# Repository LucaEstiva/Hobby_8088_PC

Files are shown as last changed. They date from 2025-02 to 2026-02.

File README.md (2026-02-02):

# Hobby_8088_PC
Studio e progetti di un PC basato su processore Intel 8088

> E' un progetto realizzato nel tempo libero, quindi ancora incompleto, ma, viste le risorse disponibili, sicuramente funzionante.
> D'altro canto sarebbe sufficiente "copiare" dagli schemi forniti l'intera circuiteria ed assemblare cosi il PC. Tuttavia lo scopo
> del progetto è quello di capire l'architettura del PC XT IBM e, divertirsi con la logica dell'architettura, aggiornarla, oppure volendo,
> modificarla a piacere.

## Fonti:
-  https://it.wikipedia.org/wiki/IBM_Personal_Computer_XT
-  https://www.vlsisystemdesign.com/propagation-delay-of-cmos-inverter/

## Riferimenti:
-  https://www.youtube.com/@breadboardinglabs
-  https://www.youtube.com/@BenEater
-  https://www.youtube.com/@SladorSoft
-  https://www.youtube.com/@elijahmmiller
-  https://www.youtube.com/@alexthelion335
-  https://www.youtube.com/@JohnsBasement
-  https://www.youtube.com/@elijahmmiller
-  ---
-  https://www.youtube.com/@adriansdigitalbasement
-  https://www.youtube.com/@PsychogenicTechnologies
-  https://www.youtube.com/@DrMattRegan
-  https://www.youtube.com/@KludgesFromKevinsCave
-  https://www.youtube.com/@nesoacademy
-  ---

-  https://www.zimmers.net/
-  https://github.com/skiselev
-  https://www.malinov.com/sergeys-projects/

-  ---
- [Digikey FPGA](https://www.youtube.com/watch?v=lLg1AgA2Xoo&list=PLEBQazB0HUyT1WmMONxRZn9NmQ_9CIKhb&ab_channel=DigiKey)
- https://www.minuszerodegrees.net/

- https://archive.org/
- https://archive.org/details/practicaldesignu0000pell/page/n1/mode/2up

- https://www.electronics-tutorials.ws/oscillator/crystal.html
- ---
# e molti molti altri. Grazie !
  
## Software utili ( solo alcuni, lista non aggiornata... ):

- [Logicly](https://logic.ly/demo/)
- [Kicad](https://www.kicad.org/) - CAD Utilizzato per la realizzazione degli schemi elettrici ( e circuiti stampati )
- [Circuitverse Simulator](https://circuitverse.org/simulator) - Importare i file dalla cartella Simulatore_Logica

## Simulazioni
[Proteus 8](https://www.labcenter.com/free-trial/)

## OS
[OSDev.org](https://wiki.osdev.org/Expanded_Main_Page)

## Libri:

- [The 80x86 IBM PC and compatible computers. Volumes I & II, Assembly language, design, and interfacing](https://archive.org/details/80x86ibmpccompat0001mazi/page/n1/mode/2up)

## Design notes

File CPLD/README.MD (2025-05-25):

# COMPLEX PROGRAMMABLE LOGIC DEVICE ( CPLD )

# Preambolo

Per ridurre il numero di componenti e la complessità del cablaggio, visto che per la realizzazione del progetto si utilizzeranno una o più Bredboard,
è piu che plausibile utilizzare le logiche programmabili.
I costruttori di personal computer da anni utilizzano questo tipo di dispositivi riducendo complessità e costi produttivi.

Ridurre il numero di fili che costituiscono le connessioni tra i vari circuiti integrati è sicuramente una buona cosa.

La qualità dei contatti ( considerando come qualità una connessione con resistenza minima ) non è garantita. Riducendo il
numero di connessioni è possibile ridurre la resistenza e le problemeatiche dovute a contatti non ottimali dovuti alla
realizzazione meccanica ( caratteristiche meccaniche delle connessioni ), e alla qualità dei materiali.

La resistenza provoca una caduta di tensione ( Legge di Ohm V = R * I ). Le logiche di tipo TTL distinguono un valore logico 1
da un livello logico 0 solo se la tensione raggiunge il valore necessario ( >= 2,5~ Volt ).

La qualità dei contatti non è garantita neppure nelle schede standard PCB, ( saldature, ossidazione ) infatti molto spesso
le saldature dei componenti tendono a rompersi o a deteriorarsi aumentando cosi la resistenza tra pista in rame e terminali dei
componenti o addirittura l'interruzione della conessione stessa.

I terminali dei compomenti, predendo come esempio il loro inserimento negli "zoccoli o socket", tendono a creare problemi dovuti all'ossidazione.
I computer più vecchi in disuso e posti in ambienti relativamente umidi ( succede spesso nei vecchi Commodore ), smettono di funzionare
proprio a causa di questo inconveniente.

Playstation 3 ( caso eclatante ma non assolutamente isolato ) soffriva di rotture delle saldature dovute alla dilatazione dei
materiali, i quali, espandendosi e ritirandosi a causa del calore prodotto da alcuni circuiti integrati, interrompevano la connessione
tra terminali e PCB, causando malfunzionamento o il guasto totale della macchina.

Inoltre le correnti ad "alte" frequenzea tendono, passando attraverso i cavetti ( induttanze, Correnti indotte, Legge di Faraday ), a generare "rumore". Questo "rumore" potrebbe influenzare i segnali che transitano attraverso i cavetti posti vicini, per tutta la loro lunghezza. Più connessioni dunque potrebbero creare disturbi incontrollati.

E' da ricordare che i cavi sono per lora stessa natura dei resistori.

SE QUESTI FATTORI NON FOSSERO CONSIDERATI CON IL DOVUTO RIGUARDO, POTREBBERO VERIFICARSI SPORADICI MALFUNZIOMANTI O IL MALFUNZIONAMENTO TOTALE.

OK, detto questo, ( la spiegazione scientifica ), passiamo alla parte divertente !

Utilizzando il software Altera ( Intel ) Quartus II è possibile "progettare" graficamente il funzionamento del dispositivo CPLD.
Inoltre sono fornite librerie che contengono molti circuiti logici di base, quindi è possibile posizionare questi circuiti nel
grafico del funzionamento del dispositivo, realizzare, sempre graficamente le connesioni dei vari terminali ed il gioco è fatto.

La serie 7000 di Altera è pienamente compatibile con i livelli di tensione, 5 Volt, dei vecchi processori 8088.

Il tempo di propagazione dei segnali propri dei semiconduttori porte logiche, sono pienamente rispettati.

Le correnti prelevabili da ogni singolo terminale sono sufficienti, se si tengono in considerazione le problematiche descritte sopra.

## Altera serie 7000

> [!NOTE]
> Non è disponibile un adattatore PLCC68 DIP68 o PLC84 DIP84. Il numero di porte di una singola logica programmabile non
> è sufficiente per gestire tutti i segnali necessari. Per il momento ne verrano utilizzate due. Successivamente verrà utilizzata una logica
> programmabile con package 100-Pin TQFP.

EPM7032SLC44

Costo irrisorio.
Programmabile via JTag ( Altera USB Blaster ).
Compatibile con logica TTL 5 Volt.
Velocità di gestione dei segnali pienamente compatibile con le frequenze utilizzate.

## Software per la programmazione datato ma gratuito.

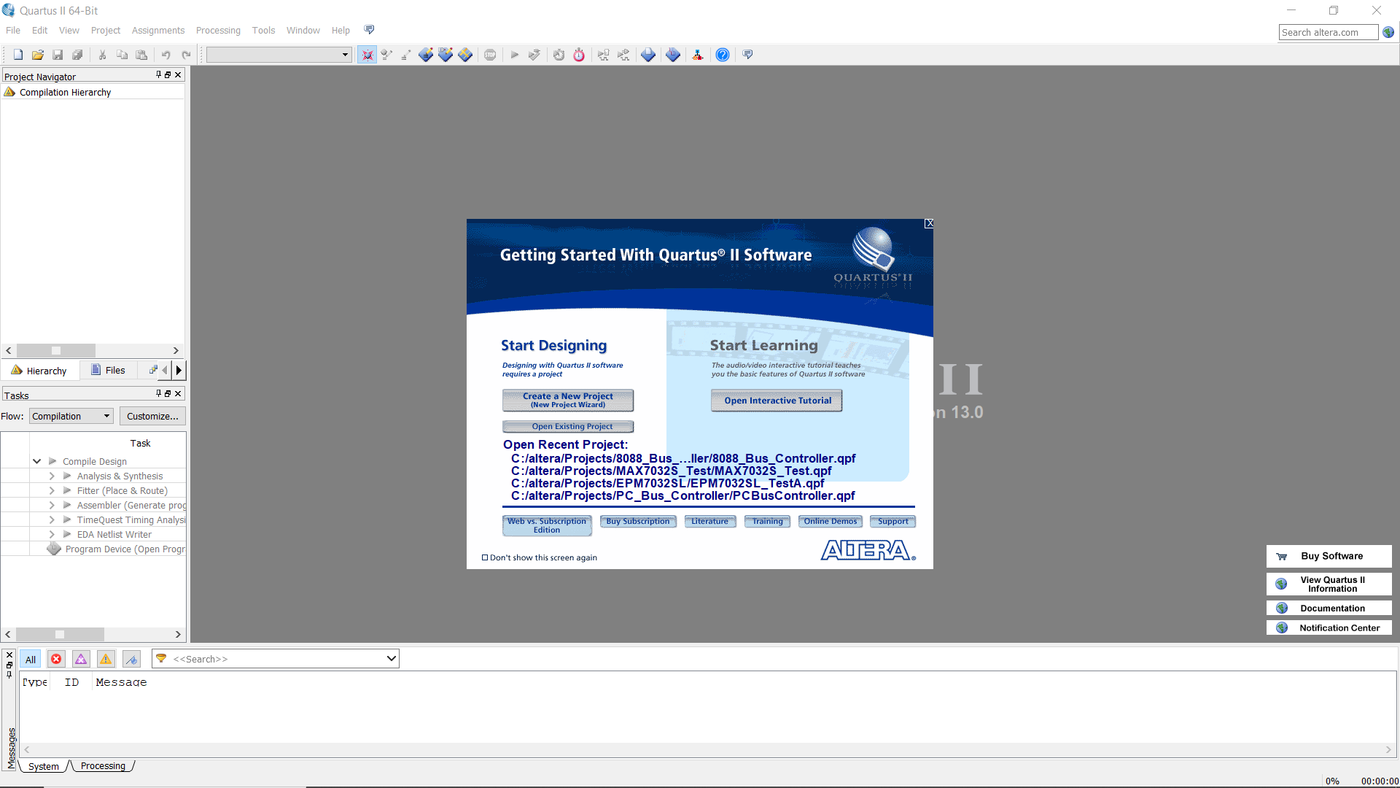
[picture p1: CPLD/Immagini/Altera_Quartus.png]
Altera ( Intel ) Quartus Web 13


DOWNLOAD:
[Datasheet, Manuali, Software](https://drive.google.com/drive/folders/0B2-T0Hc3d6D9NHljNFdQeFpJUWc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)

[QUARTUS TUTORIAL](https://www.youtube.com/watch?v=a8JAkKhxlQI&list=PL57F1D26AD6D50FA7&index=1)

## Programmatore JTag Altera

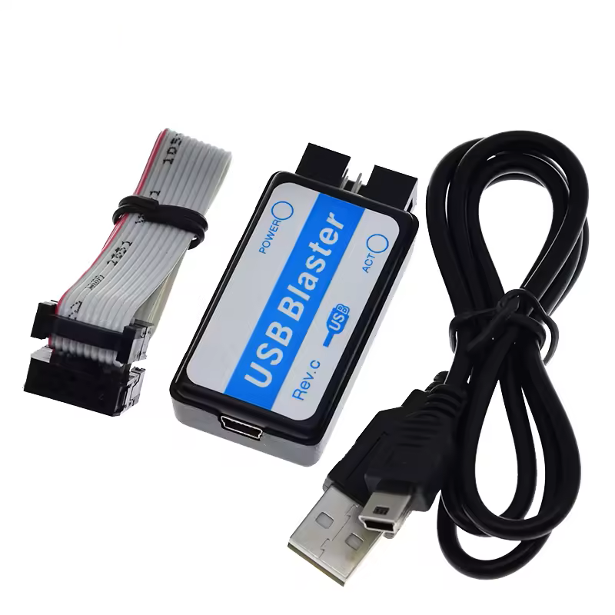
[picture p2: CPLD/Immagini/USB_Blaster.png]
USB Blaster


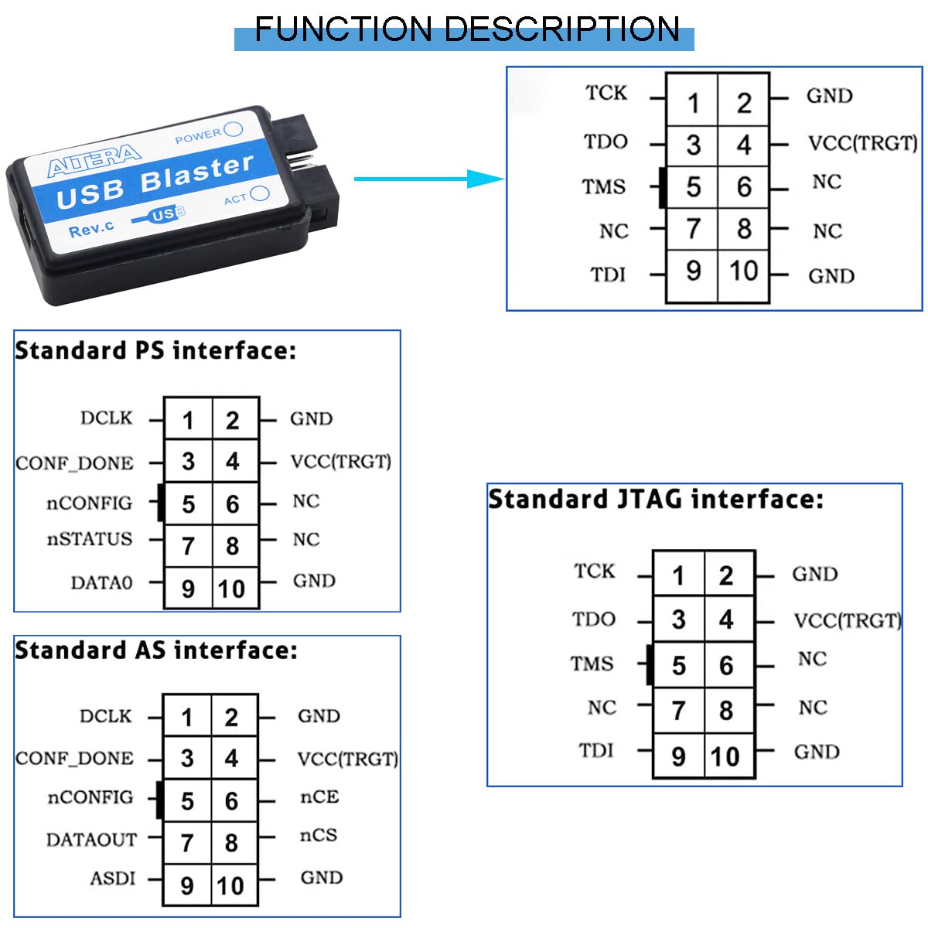
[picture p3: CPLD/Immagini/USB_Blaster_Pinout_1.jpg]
USB Blaster specifiche terminali ( Pinout )


[Altera USB Blaster](https://it.aliexpress.com/item/1005006358681875.html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)

# Adattatore PLCC44 to DIP44

PLCC44toDIP44

[PLCC44 to DIP44](https://it.aliexpress.com/item/1005007005553613.html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)

## COSI SI PUO' DIRE CHE UN'ALTRO PROBLEMA E' RISOLOTO!

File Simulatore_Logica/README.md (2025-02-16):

# SIMULATORE CIRCUITI INTEGRATI DIGITALI ( LOGICA )

https://circuitverse.org/simulator

## Esempi:
- https://circuitverse.org/users/55734/projects/74ls74-61af951a-744b-4180-bd07-4924772b58ce
- https://circuitverse.org/simulator/vending_machine_ssi

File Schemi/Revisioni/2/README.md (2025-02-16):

# TUTTI GLI INTEGRATI LOGICI SONO DELLA SERIE AHCT o F !

Negli schemi elettrici sono stati utilizzati simboli relativi a IC ( Integrate Circuit ) della seire LS solo perchè
i "simboli" e le loro piedinature sono compatibili. Aggiornerò nelle revisioni successive...

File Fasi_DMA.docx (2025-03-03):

# Fasi DMA

## Vengono generati i segnali:

HRQ Il segnale ( pin 10 8237A-5 ) viene portato a livello logico ALTO. Il segnale è utilizzato per richiedere alla CPU l’accesso al BUS.

La CPU non gestisce direttamente il segnale. Il segnale raggiunge la logica dedicata Bus Arbitration and Wait Logic

La circuiteria del Bus Arbitration and Wait Logic è responsabile della corretta generazione dei segnali necessari e delle tempistiche alla quale i segnali devono essere generati ( WAIT STATES ).

I segnali devono essere sincronizzati relativamente alle specifiche dei chip utilizzati CPU, 82C84A

DMAAEN Il segnale viene portato a livello logico BASSO. Il segnale toglie il controllo dei segnali MEMR , MEMW , IOR , IOW , al chip 8288 ( Bus Controller ) e li forza a livello logico ALTO.

Abilita il chip dell’ ADDRESS BUS relativo al DMA, ovvero collega il DMA all’ ADDRESS BUS.

AENBRD Il segnale ( pin 6 8288 AEN ) viene portato a livello logico ALTO. Il segnale disabilita i chip dell’ ADDRESS BUS relativo alla CPU, ovvero scollega la CPU dal BUS ADDRESS BUS.

AEN Il segnale ( pin 15 8288 CEN ) viene portato a livello logico BASSO.

DEN Il segnale ( pin 16 8288 DEN ) scollega la CPU dal BUS DATA BUS.

HOLDA Il segnale ( pin 7 8237A-5 HLDA ) viene portato a livello logico ALTO. Il segnale informa il chip DMA del fatto che il BUS è stato rilasciato dalla CPU

RDYTODMA Il segnale ( pin 6 8237A-5 READY ) viene utilizzato per gestire i tempi di lettura/scrittura della memoria.

DMAWAIT Il segnale ( pin 4 8284 RDY1 )

RDY /WAIT Il segnale ( pin 3 8284 AEN1 )

READY Il segnale ( pin 5 8284 READY ) è la combinazione dei segnali DMAWAIT - RDY /WAIT. Informa la CPU del fatto che il BUS è tornato nuovamente libero in quanto il DMA ha completato il proprio lavoro.

## Altri segnali:

DMACS Il segnale ( pin 11 8237A-5 CS ) viene portato a livello logico BASSO. Abilita il chip DMA per la comunicazione con la CPU. Consente di configurare i registri interni del DMA.

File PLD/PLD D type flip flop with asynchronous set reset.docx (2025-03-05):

# PLD D type flip flop with asynchronous set reset

Questo tipo di circuito viene utilizzato per gestire alcune logiche del PC.

# D type flip flop with asynchronous set reset

From SN74LS74 ( Texas Instruments ) datasheet

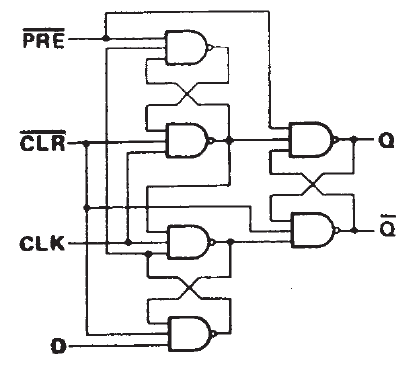
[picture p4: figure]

# D type flip flop with synchronous set reset

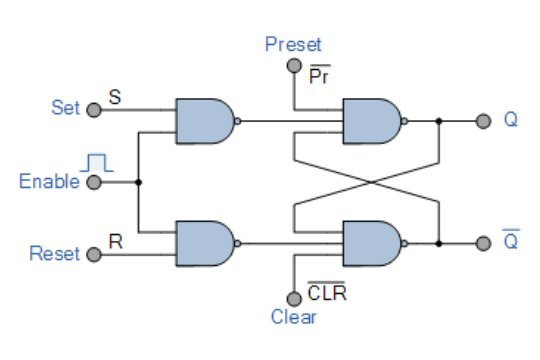
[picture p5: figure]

L’ingresso CLEAR ( CLR ) serve per assicurarsi che l'uscita Q venga sovrascritta con un livello logico 0 ( BASSO ).

L’ingresso PRESET ( PRE ) serve per assicurarsi che l’uscita Q venga sovrascritta con un livello logico 1 ( ALTO ).

Se uno o entrambe gli ingressi CLEAR o PRESET, si trovano a livello logico 0 ( BASSO ), l’ingresso CLOCK non viene considerato. In questi stati di CLEAR e/o PRESET il livello logico delle uscite non cambia mai.

In qualsiasi momento l’ingresso CLEAR viene portato a livello logico 0, non viene considerato lo stato dell’ingresso D. L’uscita Q viene portata a livello logico 0 ( BASSO ), l’uscita !Q viene portata a livello logico 1 ( ALTO ).

In qualsiasi momento l’ingresso PRESET viene portato a livello logico 0, non viene considerato lo stato dell’ingresso D. L’uscita Q viene portata a livello logico 1 ( ALTO ), l’uscita !Q viene portata a livello logico 0 ( BASSO ).

Se entrambe gli ingressi CLEAR e PRESET si tronano a livello logico 1 ( ALTO ), un fronte di salita sull’ingresso CLOCK, copia lo stato dell’ingresso D sull’uscita Q.

L’uscita !Q è sempre l’inverso ( complementare ) dell’uscita Q.

PER UNA DESCRIZIONE PIU’ DETTAGLIATA DEL CHIP 74LS74 e DEI RELATIVI FLIP FLOP IN ESSO CONTENUTI VEDERE IL RELATIVO DATASHEET.

PLD Per ricreare il Flip Flop

Solo alcune PLD supportano alcune funzionalità necessarie per ricreare facilmente la logica del Flip Flop. Dal manuale di WinCupl ( doc0737.pdf è possibile verificare quale serie di PLD si presta meglio alla realizzazione de

WinCupl EXTENSIONS ( Vedere il documento doc0737.pdf )

.D D input of D-type flip-flop

.R R input of SR-type output flip-flop

.S S input of SR-type output flip-flop

.SP Synchronous preset of flip-flop

.AP Asynchronous preset of flip-flop

.SR Synchronous reset of flip-flop

.AR Asynchronous reset of flip-flop

.SP Extension

The .SP extension is used to set the Synchronous Preset of a register to an expression. For example. the equation:

Y.SP = A & B ; /* A and B are inputs */

causes the output Y to be preset synchronous with the local clock used in the macro cell when inputs A and B are true.

This feature is supported on Atmel ATF22V10B, ATV750/B and ATV2500/B devices which share Synchronous preset product terms.

.AP Extension

The .AP extension is used to set the Asynchronous Preset of a register to an expression. For example. the equation "Y.AP = A&B;" causes the register to be asynchro

nously preset when A and B are logically true.

This feature is supported on the Atmel ATF1500 family of devices.

.OE Extension

The .OE extension is used to specify a product term driven output enable signal. It is required for using bi-directional I/O and the individually programmable output-enable

product terms available on Atmel ATV750/B, ATV2500/B and ATF1500 family of devices.

Atmel Devices which have a pin-controlled OE inputs, such as the ATF1500 family also use this suffix.

.D Extension

The .D extension is used to specify the D input to a D-type register. This options causes the compiler to configure the macrocells in the Atmel PLD device to D-type reg isters.

For Atmel PLD’s such as the ATF16V8B/20V8B/22V10B, ATV750/B and ATV2500/B the .D extension must be used for registered logic. Otherwise, CUPL will generate an error.

.AR Extension

The .AR extension is used to define the expression for Asynchronous Reset for a reg ister. This is used in devices that have one or more product terms connected to the

Asynchronous reset of the register.

Devices which have a pin-controlled reset inputs, such as the Atmel ATF1500 family also use this suffix.

Name Flip_Flop;

PartNo 00;

Date 04/03/2025;

Revision 01;

Designer Engineer;

Company None;

Assembly None ;

Location ;

Device g22v10;

/* INPUT */

PIN 1 = clock;

PIN 2 = data;

PIN 3 = !clr;

PIN 4 = !pre;

PIN 13 = !outen;

/* OUTPUT */

PIN 14 = Q1;

PIN 15 = Q2;

/* Logic Equations */

Q1.OE = outen;

Q2.OE = outen;

Q1.SP = pre;

Q1.AR = clr;

Q1.D = data;

Q2 = !Q1;

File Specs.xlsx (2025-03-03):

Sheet: ROM-RAM
RAM | A0-A18 | Adrress | 19 Bit | 0 | 111 11111111 11111111 | 524287
 | A19 | Chip Select-Chip Enable
 |  |  | 20Bit | 0 | 1111 11111111 11111111 | 1048575
ROM

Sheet: IO_Address_Map
000 | 00F | DMA chip 8237A-5
020 | 021 | Interrupt 8259A
040 | 043 | Timer 8253-5
060 | 063 | PPI 8255A
080 | 083 | DMA Page Registers
0Ax* |  | NMI Mask Register
0Cx |  | Reserved
0Ex |  | Reserved
100 | 1FF | Not usable
200 | 20F | Game Control
210 | 217 | Expansion Unit
220 | 24F | Reserved
278 | 27F | Reserved
2F0 | 2F7 | Reserved
2F8 | 2FF | Asyncronous Communications ( secondary )
300 | 31F | Prototype card
320 | 32F | Fixed Disk
378 | 37F | Printer
380 | 38C** | SDLC Communications
380 | 389** | Binary Syncronous Communications ( Secondary )
3A0 | 3A9 | Binary Syncronous Communications ( Primary )
3B0 | 3BF | IBM Monochrome Display/Printer
3C0 | 3CF | Reserved
3D0 | 3DF | Color/Graphics
3E0 | 3F7 | Reserved
3F0 | 3F7 | Diskette
3F8 | 3FF | Asyncronous Communications ( Primary )
* At power-on time, the NON MASK Interrupt into the 8088 in masked OFF. This mask bit can be set and reset through system software as follows
Set mask: | Write hex 80 to I/O Address hex A0 ( Enable NMI )
Clear mask: | Write hex 00 to I/O Address hex A0 ( Disable NMI )
** SLDC Communications and Secondary Binary Syncronous Communications cannot be used toghether because their hex address overlap
 |  | A8, A9 Address bits
 |  | 010000000 | 80
 |  | 100000000 | 100
 |  | 110000000 | 180

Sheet: Interrupt
0 | Timer
1 | Keyboard
2 | Reserved
3 | Asynchronouns Communications ( Secondary )
 | SDLC Communications
 | BSC ( Secondary )
4 | Asynchronouns Communications ( Primary )
 | SDLC Communications
 | BSC ( Primary )
5 | Fixed Disk
6 | Diskette
7 | Printer

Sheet: Memory_Map
 |  |  |  |  | CTRL+Addr Bits |  |  |  | Address bits
0 | 00000 | 16K to 64K Read/Write Memory on System Board |  |  | 19 | 18 | 17 | 16 | 15 | 14 | 13 | 12 | 11 | 10 | 9 | 8 | 7 | 6 | 5 | 4 | 3 | 2 | 1 | 0
16K | 04000 |  |  |  | 0 | 0 | 0 | 0 | 0 | 1 | 0 | 0 | 0 | 0 | 0 | 0 | 0 | 0 | 0 | 0 | 0 | 0 | 0 | 0
32K | 08000 |  |  |  | 0 | 0 | 0 | 0 | 1 | 0 | 0 | 0 | 0 | 0 | 0 | 0 | 0 | 0 | 0 | 0 | 0 | 0 | 0 | 0
48K | 0C000 |  |  |  | 0 | 0 | 0 | 0 | 1 | 1 | 0 | 0 | 0 | 0 | 0 | 0 | 0 | 0 | 0 | 0 | 0 | 0 | 0 | 0
64K | 10000 | Up to 384K Read/Write Memory in I/O channel Up to 384K in I/O Channel |  |  | 0 | 0 | 0 | 1 | 0 | 0 | 0 | 0 | 0 | 0 | 0 | 0 | 0 | 0 | 0 | 0 | 0 | 0 | 0 | 0
80K | 14000
96K | 18000
112K | 1C000 |  |  |  | 0 | 0 | 0 | 1 | 1 | 1 | 0 | 0 | 0 | 0 | 0 | 0 | 0 | 0 | 0 | 0 | 0 | 0 | 0 | 0
128K | 20000 |  |  |  | 0 | 0 | 1 | 0 | 0 | 0 | 0 | 0 | 0 | 0 | 0 | 0 | 0 | 0 | 0 | 0 | 0 | 0 | 0 | 0
144K | 24000
160K | 28000
176K | 2C000 |  |  |  | 0 | 0 | 1 | 0 | 1 | 1 | 0 | 0 | 0 | 0 | 0 | 0 | 0 | 0 | 0 | 0 | 0 | 0 | 0 | 0
192K | 30000 |  |  |  | 0 | 0 | 1 | 1 | 0 | 0 | 0 | 0 | 0 | 0 | 0 | 0 | 0 | 0 | 0 | 0 | 0 | 0 | 0 | 0
208K | 34000
224K | 38000
240K | 3C000 |  |  |  | 0 | 0 | 1 | 1 | 1 | 1 | 0 | 0 | 0 | 0 | 0 | 0 | 0 | 0 | 0 | 0 | 0 | 0 | 0 | 0
256K | 40000 |  |  |  | 0 | 1 | 0 | 0 | 0 | 0 | 0 | 0 | 0 | 0 | 0 | 0 | 0 | 0 | 0 | 0 | 0 | 0 | 0 | 0
272K | 44000
288K | 48000
304K | 4C000 |  |  |  | 0 | 1 | 0 | 0 | 1 | 1 | 0 | 0 | 0 | 0 | 0 | 0 | 0 | 0 | 0 | 0 | 0 | 0 | 0 | 0
320K | 50000 |  |  |  | 0 | 1 | 0 | 1 | 0 | 0 | 0 | 0 | 0 | 0 | 0 | 0 | 0 | 0 | 0 | 0 | 0 | 0 | 0 | 0
336K | 54000
352K | 58000
368K | 5C000 |  |  |  | 0 | 1 | 0 | 1 | 1 | 1 | 0 | 0 | 0 | 0 | 0 | 0 | 0 | 0 | 0 | 0 | 0 | 0 | 0 | 0
384K | 60000 |  |  |  | 0 | 1 | 1 | 0 | 0 | 0 | 0 | 0 | 0 | 0 | 0 | 0 | 0 | 0 | 0 | 0 | 0 | 0 | 0 | 0
400K | 64000
416K | 68000
432K | 6C000 |  |  |  | 0 | 1 | 1 | 0 | 1 | 1 | 0 | 0 | 0 | 0 | 0 | 0 | 0 | 0 | 0 | 0 | 0 | 0 | 0 | 0
448K | 70000 |  | ROM ADDRESS SEL |  | 0 | 1 | 1 | 1 | 0 | 0 | 0 | 0 | 0 | 0 | 0 | 0 | 0 | 0 | 0 | 0 | 0 | 0 | 0 | 0
464K | 74000
480K | 78000
496K | 7C000 |  |  |  | 0 | 1 | 1 | 1 | 1 | 1 | 0 | 0 | 0 | 0 | 0 | 0 | 0 | 0 | 0 | 0 | 0 | 0 | 0 | 0
512K | 80000 |  | RAM 2 SEL |  | 1 | 0 | 0 | 0 | 0 | 0 | 0 | 0 | 0 | 0 | 0 | 0 | 0 | 0 | 0 | 0 | 0 | 0 | 0 | 0 | 9FFFF
528K | 84000
544K | 88000
560K | 8C000 |  |  |  | 1 | 0 | 0 | 0 | 1 | 1 | 0 | 0 | 0 | 0 | 0 | 0 | 0 | 0 | 0 | 0 | 0 | 0 | 0 | 0
576K | 90000
592K | 94000
608K | 98000
624K | 9C000 |  |  |  | 1 | 0 | 0 | 1 | 1 | 1 | 0 | 0 | 0 | 0 | 0 | 0 | 0 | 0 | 0 | 0 | 0 | 0 | 0 | 0
640K | A0000 | 128K Reserved |  |  | 1 | 0 | 1 | 0 | 0 | 0 | 0 | 0 | 0 | 0 | 0 | 0 | 0 | 0 | 0 | 0 | 0 | 0 | 0 | 0
656K | A4000
672K | A8000
688K | AC000 |  |  |  | 1 | 0 | 1 | 0 | 1 | 1 | 0 | 0 | 0 | 0 | 0 | 0 | 0 | 0 | 0 | 0 | 0 | 0 | 0 | 0
704K | B0000 | Monochrome |  | Display Buffer ( 16K Bytes )
720K | B4000
736K | B8000 | Color/Graphics
752K | BC000 |  |  |  | 1 | 0 | 1 | 1 | 1 | 1 | 0 | 0 | 0 | 0 | 0 | 0 | 0 | 0 | 0 | 0 | 0 | 0 | 0 | 0
768K | C0000 |  |  | VGA | 1 | 1 | 0 | 0 | 0 | 0 | 0 | 0 | 0 | 0 | 0 | 0 | 0 | 0 | 0 | 0 | 0 | 0 | 0 | 0 | VGA BIOS usually mapped to 0xC0000 to 0xC7FFF
784K | C4000
800K | C8000 | Fixed Disk Control |  |  | 1 | 1 | 0 | 0 | 1 | 0 | 0 | 0 | 0 | 0 | 0 | 0 | 0 | 0 | 0 | 0 | 0 | 0 | 0 | 0
816K | CC000 | 192K Read Only Memory Expansion and Control
832K | D0000
848K | D4000
864K | D8000
880K | DC000
896K | E0000
912K | E4000
928K | E8000
944K | EC000 |  |  |  | 1 | 1 | 1 | 0 | 1 | 1 | 0 | 0 | 0 | 0 | 0 | 0 | 0 | 0 | 0 | 0 | 0 | 0 | 0 | 0
960K | F0000 | 64K Base System ROM | ROM ADDRESS SEL |  | 1 | 1 | 1 | 1 | 0 | 0 | 0 | 0 | 0 | 0 | 0 | 0 | 0 | 0 | 0 | 0 | 0 | 0 | 0 | 0
976K | F4000
992K | F8000
1008K | FC000 |  |  |  | 1 | 1 | 1 | 1 | 1 | 1 | 0 | 0 | 0 | 0 | 0 | 0 | 0 | 0 | 0 | 0 | 0 | 0 | 0 | 0

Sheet: DMA
 | Min Address | Max Address
Page 0 | 0 | 1111111111111111 | FFFF
Page 1 | 10000000000000000 | 11111111111111111 | 1FFFF
Page 2 | 10 00000000 00000000 | 11 11111111 11111111 | 3FFFF
Page 3 | 100 00000000 00000000 | 111 11111111 11111111 | 7FFFF
Page 4 | 1000 00000000 00000000 | 1111 11111111 11111111 | FFFFF

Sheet: RAS_CAS
RAS (Row Address Strobe) and CAS (Column Address Strobe) are essential signals used in DDR (Double Data Rate) memory to access data stored in specific rows and columns within the memory array. These concepts are fundamental to how DDR memory reads and writes data efficiently.
CAS0 |  | 0
 |  | 1111111111111 | 0x1FFF | 8191
CAS1 | Bit 14 | 10000000000000 | 0x2000 | 8192
 |  | 11111111111111 | 0x3FFF | 16383 | 16383
CAS2 | Bit 15 | 100000000000000 | 0x4000 | 16384
 |  | 101111111111111 | 0x5FFF | 24575 | 24575
CAS3 |  | 110000000000000 | 0x6000 | 24576
 |  | 111111111111111 | 0x7FFF | 32767 | 32768

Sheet: Port
210
211
212
213

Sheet: Foglio3
Bus Arbitration - Wait Logic INPUT
I/O CH RDY | ISA BUS CHANNEL 1-7 READY
XIOR | READ FROM MEM, I/O - IOR BUFFERED
XIOW | WRITE TO MEM, I/O - IOW BUFFERED
DMAEN
MEMR | FROM 8288 MRDC
IOW | FROM 8288 AIOWC
MEMW | FROM 8288 AMWC
IOR | FROM 8288 IORC
 | FROM 8288 IOWC ( NC )
DACK 0 BRD | FROM 8237A-5 ( DMA ) - DACK0
XMEMR | FROM 8288 MRDC - MEMR BUFFERED
LOCK | FROM 8088
S0 | FROM 8088
S1 | FROM 8088
HRQDMA | FROM 8237A-5 ( DMA ) - HRQ
RESET | FROM 8284A - RESET
CLOCK | CLK88 BUFFERED
N.P. NPI | FROM 8087 COOPROCESSOR - INT
N.P. INST LSW | FROM 8255A-5 - PB3
PCK | CLOCK /2 ?
XD7
WRT NMI REG | FROM LOGIC
I/O CLK | CLOCK FROM ISA BUS
ENABLE I/O CLK | FROM 8255A-5 - PB5
CLK88 | FROM 8284A CLOCK GENERATOR
Bus Arbitration - Wait Logic OUTPUT
XMEMR | Enable data transfer from RAM to CPU/DMA. RAM ADDSEL complementary signal
RDY/WAIT | TO 8484A CLOCK GENERATOR
RDY TO DMA | TO 8237A-5 DMA - RDY
DMAEN | Enable data transfer from RAM/ROM etc to DMA
 | TO LS670 DMA PAGE SELECT - READ

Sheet: Control_Signal
8088
S2 | S1 | S0
0 | 0 | 0 | Interrup Acknowledge
0 | 0 | 1 | Read I/O Port
0 | 1 | 0 | Write I/O Port
0 | 1 | 0 | Halt
1 | 0 | 0 | Code Access
1 | 0 | 1 | Read Memory
1 | 1 | 0 | Write Memory
1 | 1 | 1 | Passive
HOLD ( RQ/GT0 ) |  |  | Another master is requiring a local BUS | Free ( float ) BUS and Control Lines | When HOLD goes LOW
HLDA ( RQ/GT1 ) |  |  | Bus free indicator |  | Goes LOW
SS0 ( HIGH )
RD |  |  | READ ( FLOAT IN HOLD ACKNOWLEDGE ) | Depend on the state of IO/M signal | Read from Memory or IO
WR ( LOCK ) |  |  | WRITE ( FLOAT IN HOLD ACKNOWLEDGE ) | Depend on the state of IO/M signal | Write to Memory or I/O
 |  |  | BUS Locked
IO/M ( S2 ) |  |  | I/O or Memory access ( Managed by 8288 ) ( FLOAT IN HOLD ACKNOWLEDGE )
DT/R ( S1 ) |  |  | ( Managed by 8288 ) ( FLOAT IN HOLD ACKNOWLEDGE ) |  | Used to control the direction of data flow through the receiver
DEN ( S0 ) |  |  | Data Enable Data enable for the data BUS transceiver ( Managed by 8288 ) ( FLOAT IN HOLD ACKNOWLEDGE ) | Data transmit receive
ALE ( QS0 ) |  |  | Address latch enable ( NEVER FLOATED )
INTA ( QS1 ) |  |  | Interrupt request Acknowledge
INTR |  |  | Interrupt request
NMI |  |  | Non maskable interrupt request
TEST
READY |  |  | Ack from addressed memory or I/O, data transfer can be completed
8288 BUS CONTROLLER
S2 | S1 | S0 | Status input ( When passive all HIGH ) Status from 8088 | 8288 Command
0 | 0 | 0 | Interrupt Acknowledge | INTA
0 | 0 | 1 | Read I/O Port | IORC
0 | 1 | 0 | Write I/O Port | IOWC, AIOWC
0 | 1 | 1 | HALT | NONE
1 | 0 | 0 | Code Access | MRDC
1 | 0 | 1 | Read Memory | MRDC
1 | 1 | 0 | Write Memory | MWTC, AMWC
1 | 1 | 1 | PASSIVE | NONE
ALE |  |  | Address latch enable, strobe address into the address latches
DEN |  |  | Data enable, ENABLE Data transceivers local or system bus
DT/R |  |  | Data transmit/receive, HIGH Trasmit data, LOW Receive data
AEN |  |  | Address Enable, ENABLE ADDRESS LATCHES, Enable command outputs of the 8288 Bus Controller
CEN |  |  | Command Enable, When LOW Command output and DEN PDEN are forced to inactive state
IOB |  |  | Input/Output BUS MODE, When HIGH 8288 function in I/O Bus Mode, When LOW 8288 function in System Bus Mode
AIOWC |  |  | Advanced I/O Write Command, early indication of I/O WRITE instruction
IOWC |  |  | I/O Write Command, I/O Device read from Data Bus Command
IORC |  |  | I/O Read Coomand, I/O Device write to Data Bus Command
AMWC |  |  | Advanced Memory Write Command, early indication of RAM WRITE Instruction
MWTC |  |  | Memory Write Command, Write data to memory command
MRDC |  |  | Memory Read Command, Read data from memory command
INTA |  |  | Interrupt Acknowledge, Tell an interrupting DEVICE that its interrup has been acknwoledged, It shuold drive information onto the DATA BUS
MCE/PDEN |  |  | Master Cascade Enable, occurs during an interrupt sequence, Read a cascade Address from a MASTER PIC
 |  |  | Peripheral Data Enable, ENABLE the DATA BUS TRANSCEIVERS for the I/O BUS that DEN performs for the SYSTEM BUS
DMA
CLK |  |  | Clock up to 5MHz
CS |  |  | Chip select, select the 8237A as an I/O devuce during CPU IDLE CYCLE
RESET
READY |  |  | Input used to extend the memory read and write pulse from the 8237A to accomdodate slow memory or I/O
HLDA |  |  | HOLD ACKNOWLEDGE The active HIGH Ack from the cpu indicates that the SYSTEM BUS is free
DREQ0-DREQ3 |  |  | DMA REQUEST, DMA Line to request DMA service, DREQ0 as the HIGH PRIORITY, DACK ack the DREQ signal | Polarity programmable
IOR |  |  | I/O READ, In the IDLE CYCLE
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

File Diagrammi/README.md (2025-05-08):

# Diagrammi realizzati con il software free:

- [Draw.io Web](https://app.diagrams.net/)
- [Draw.io Desktop](https://www.drawio.com/)

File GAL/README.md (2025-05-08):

# Risorse

- [GALAsm](https://github.com/daveho/GALasm)
- [Lattice ispGAL & ispLSI](https://www.ythiee.com/2023/01/08/lattice-ispgal-isplsi/)
- [GAL specific information](https://www.ythiee.com/2021/06/06/gal-specific-information/)
- [PLD Compilers](https://www.ythiee.com/2021/06/06/pld-compilers/)

- [VirtualBox](https://www.virtualbox.org/)
- [Windows XP Professional SP3](https://archive.org/details/WinXPProSP3x86)
- [Windows XP Product Key](https://github.com/Fuwn/xp)

## Alcuni articoli interessanti:
- [KIM-64](https://www.ythiee.com/2025/01/05/kim-64/)
- [GAL22V10](https://www.ythiee.com/tag/gal22v10/)

# High Performance E2CMOS PLD Generic Array Logic™

- [GAL26V12C](https://github.com/LucaEstiva/Hobby_8088_PC/blob/main/GAL/26CV12.PDF)

- [GAL20RA10](https://github.com/LucaEstiva/Hobby_8088_PC/blob/main/GAL/GAL20RA10.PDF)

## Alcune peculiarità del chip GAL 20RA10

- Reset Asincrono indipendente per ogni Flip Flop:

Each GAL20RA10 macrocell has an independent asynchronous\
reset and preset control product term. The reset and preset product\
terms are level sensitive, and will hold the flip-flop in the reset or\
preset state while the product term is active independent of the clock\
or D-inputs. It should be noted that the reset and preset term alter\
the state of the flip-flop whose output is inverted by the output\
buffer. A reset of the flip-flop will result in the output pin becoming\
a logic high and a preset will result in a logic low.\

- Sogenti clock indipenti:

An independent clock control product term is provided for each\
GAL20RA10 macrocell. Data is clocked into the flip-flop on the\
active edge of the clock product term. The use of individual clock\
control product terms allow up to ten separate clocks. These clocks\
can be derived from any pin or combination of pins and/or feedback\
from other flip-flops. Multiple clock sources allow a number of\
asynchronous register functions to be combined into a single\
GAL20RA10. This allows the designer to combine discrete logic\
functions into a single device.\

# ABEL
ABEL (Advanced Boolean Expression Language)\
Può essere utilizzato su macchina virtuale con Windows XP.
E' possibile scaricare ABEL direttamente da questo repository.

- Utilizzare ABEL GUI:

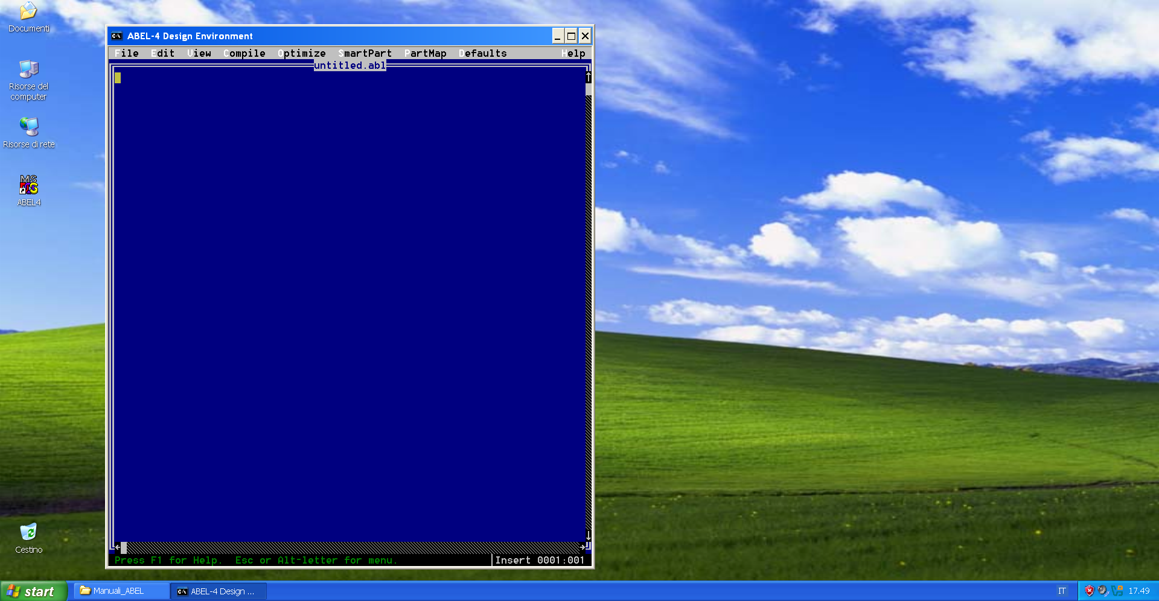
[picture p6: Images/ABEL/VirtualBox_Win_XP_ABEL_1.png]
ABEL ON XP


Per generare il file jed, sarà necessario eseguire gli step:

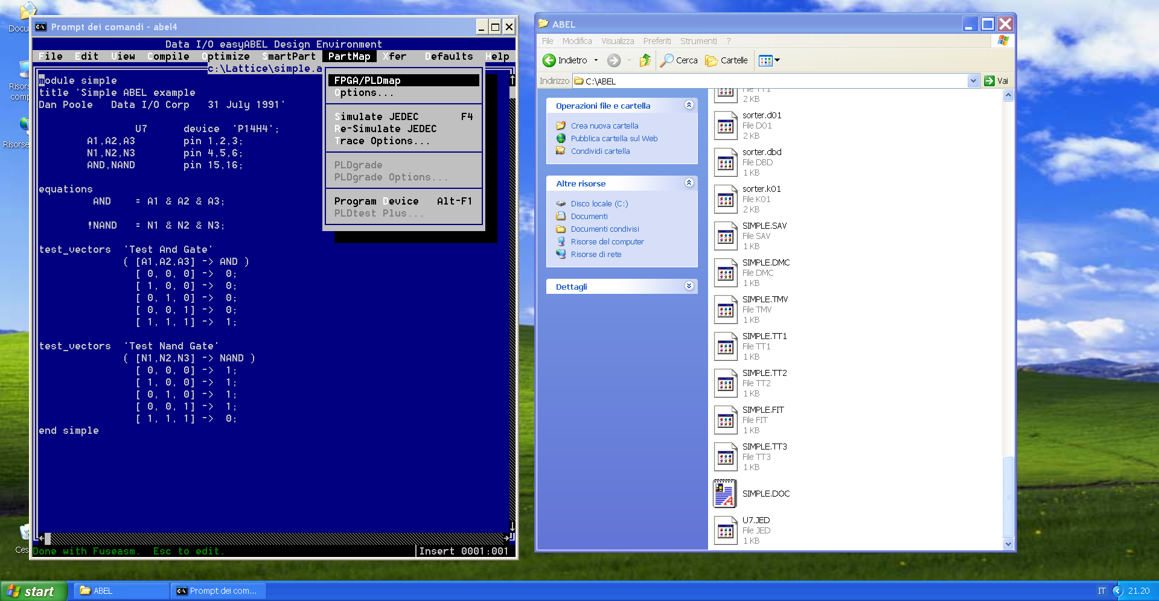
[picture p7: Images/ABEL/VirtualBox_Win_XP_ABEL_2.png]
ABEL COMPILE


- Compile
- Optimize
- Fit
- FPGA/PLDmap

Per utilizzare ABEL utlizzando la riga di comando dal prompt di MS-Dos sarà necessario aggiungere al path i seguenti percorsi ( Pannello di controllo - Sistema - Avanzate - Variabili ambiente )\

- ahdl2pla

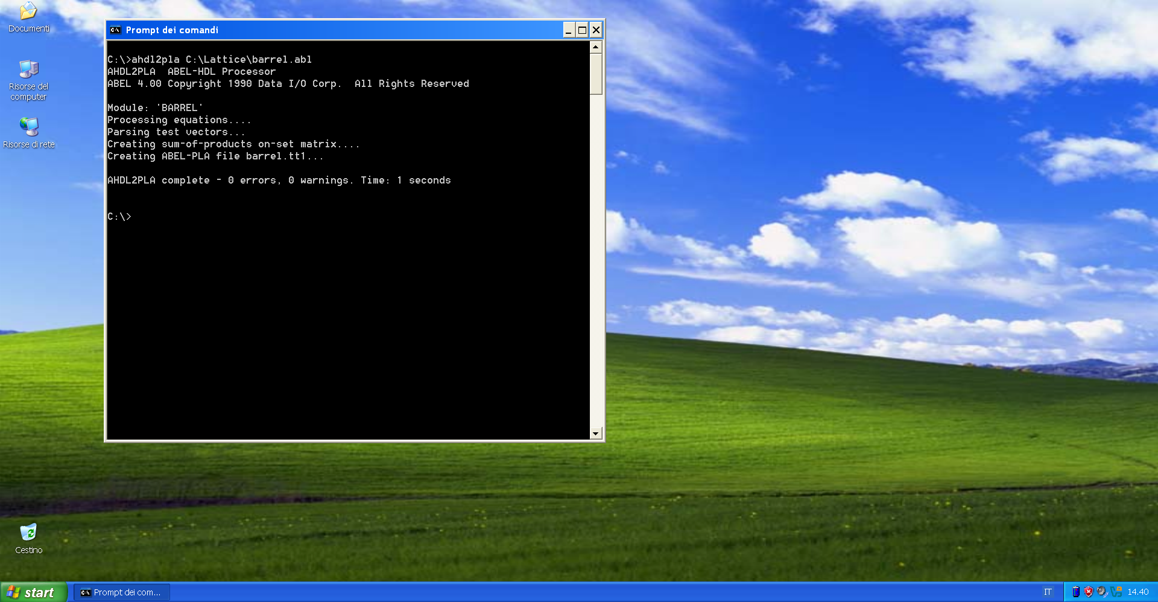
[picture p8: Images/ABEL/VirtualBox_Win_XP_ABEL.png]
ABEL ON XP


set ABELDEV=D:\ABEL\LIB4\
set PATH=%PATH%;D:\ABEL\

ovvero aggiungere al path ( Se ABEL si trova, ad esempio nella root del disco C il path sarà C:\ABEL ):\
C:\ABEL;C:\ABEL\LIB4

Quindi sarà possibile compilare un progamma:

- ahdl2pla "pathtoablfile.abl"

Aprire "editare" il file RUNME.bat ( usando un editor di testo ad esempio Notepad++, Blocco Note, Visual studio Code o altro... ) che si trova nella cartella ABEL per verificare i valori del parametri set.

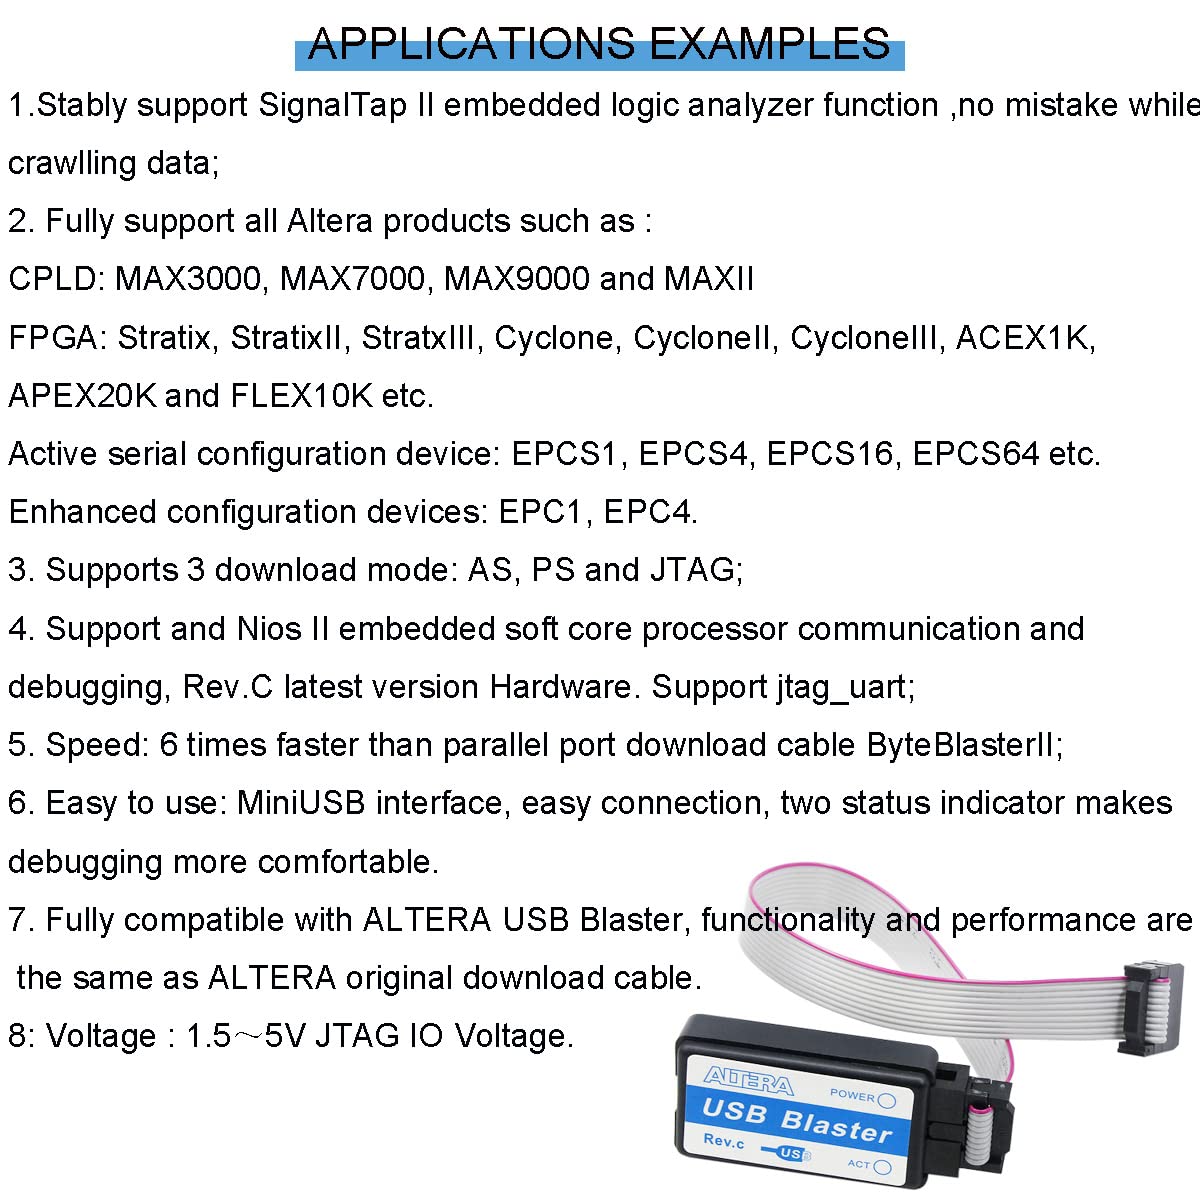
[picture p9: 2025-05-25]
CPLD/Immagini/USB_Blaster_Specifiche.jpg

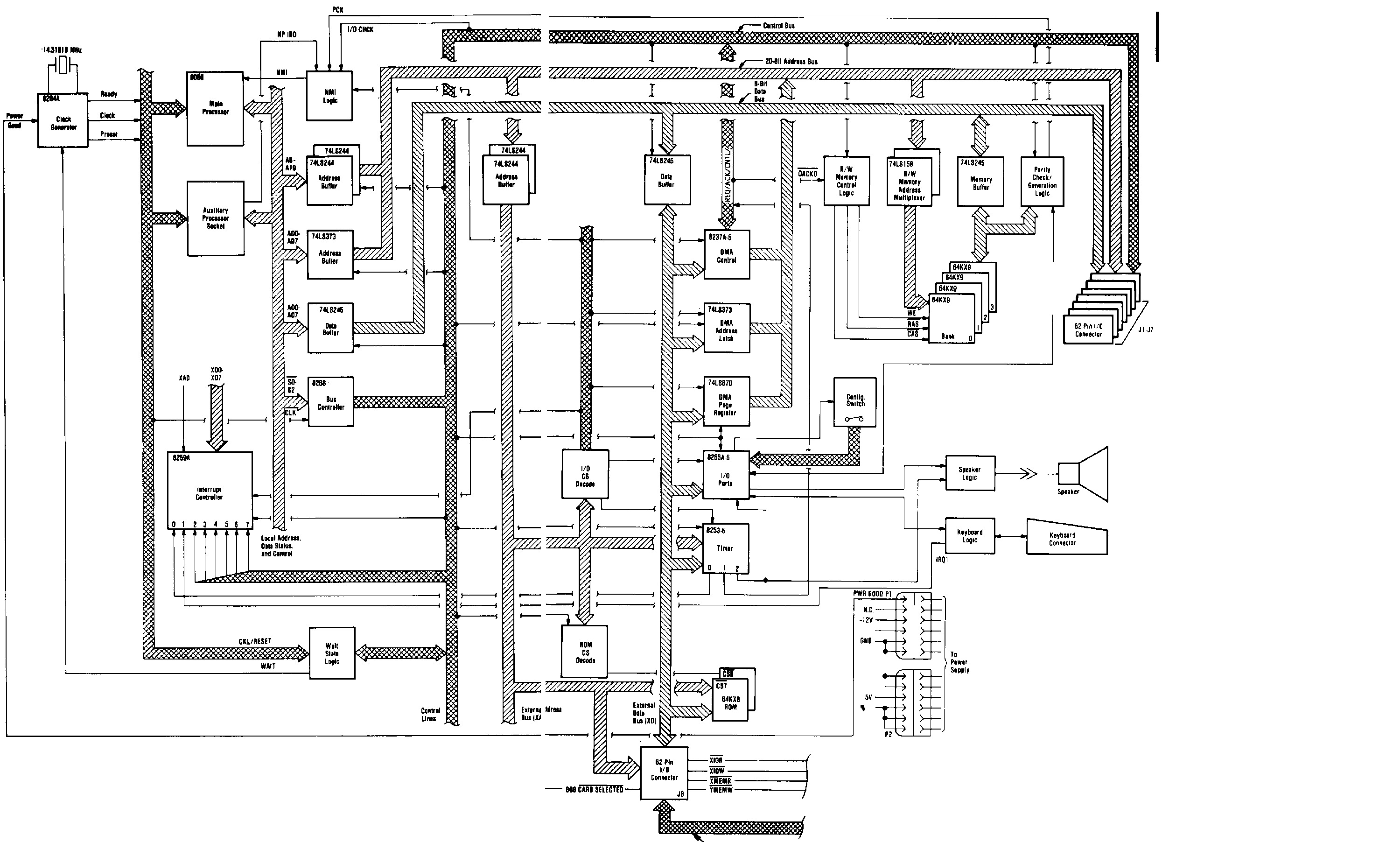
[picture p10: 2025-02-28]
System_Board_Data_Flow.jpg

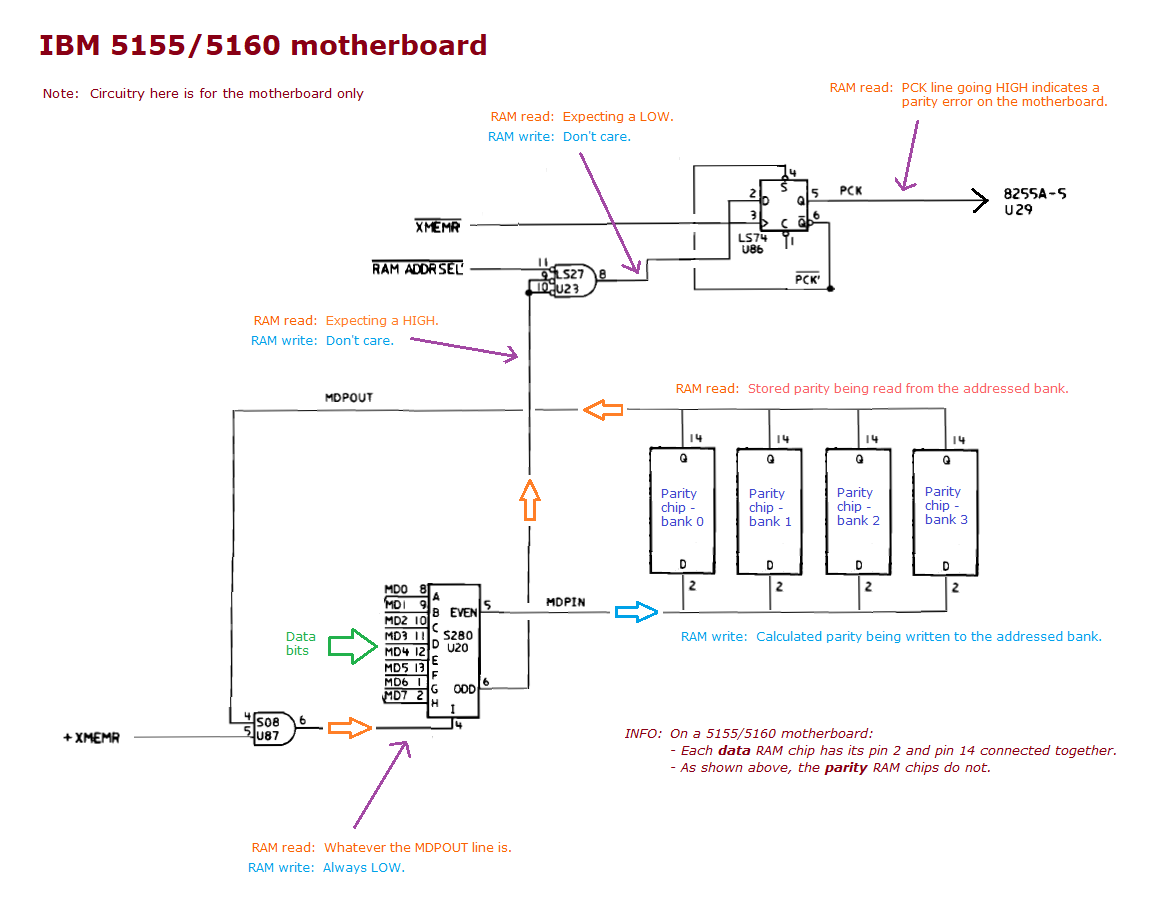
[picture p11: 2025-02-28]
Simplyfied_Diagram/IBM 5160 motherboard - RAM parity generation and comparison.png

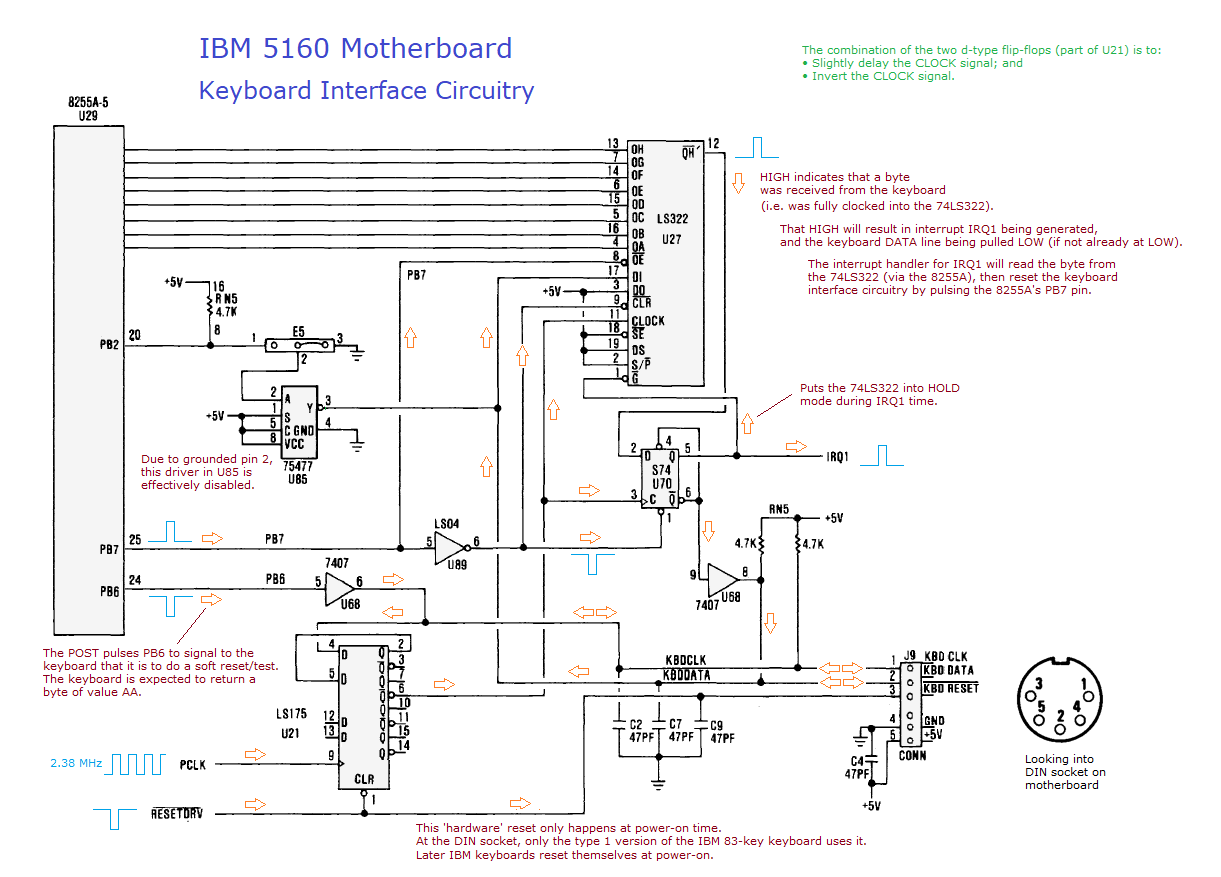
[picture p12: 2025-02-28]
Simplyfied_Diagram/IBM 5160 - Keyboard interface circuitry.png

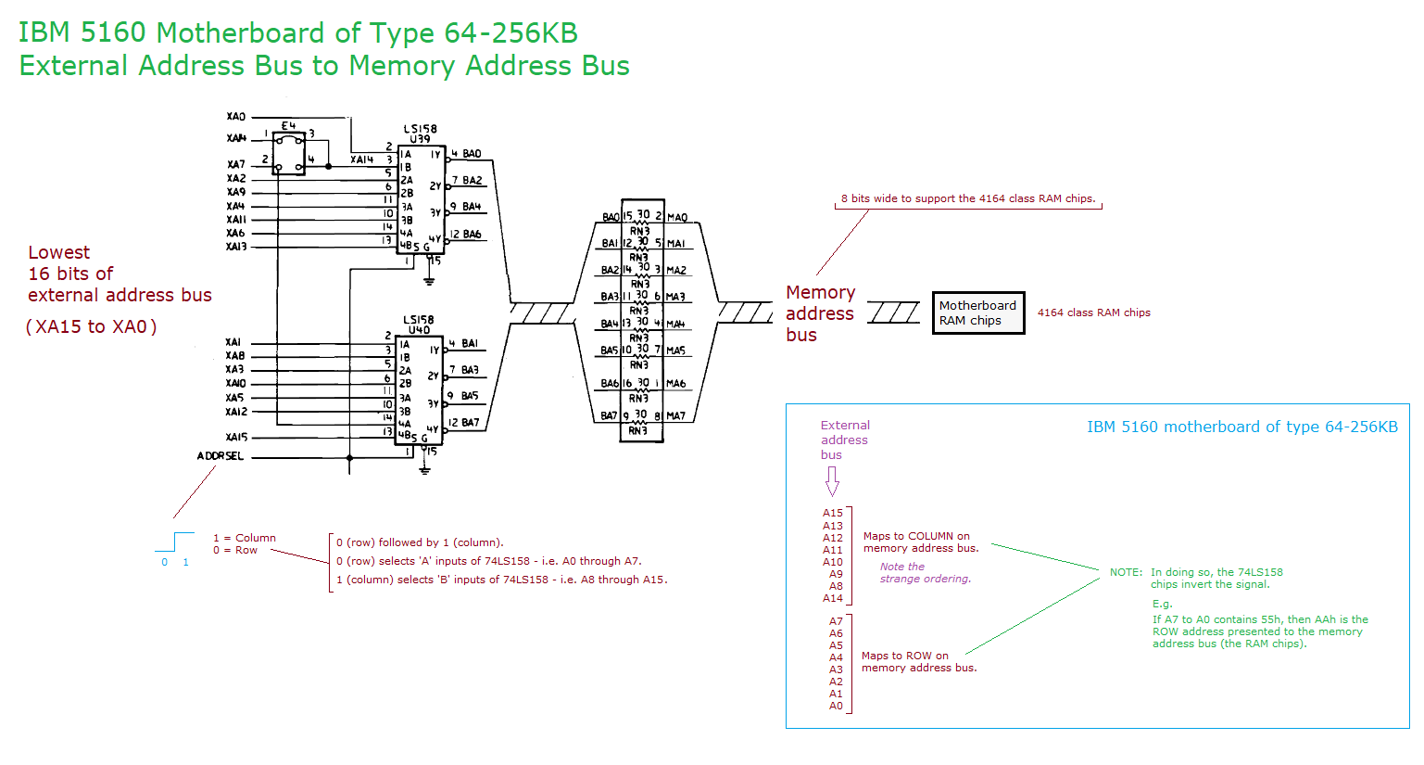
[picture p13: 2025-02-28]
Simplyfied_Diagram/IBM 5160 motherboard - 64-256KB - External address bus to memory address bus.png

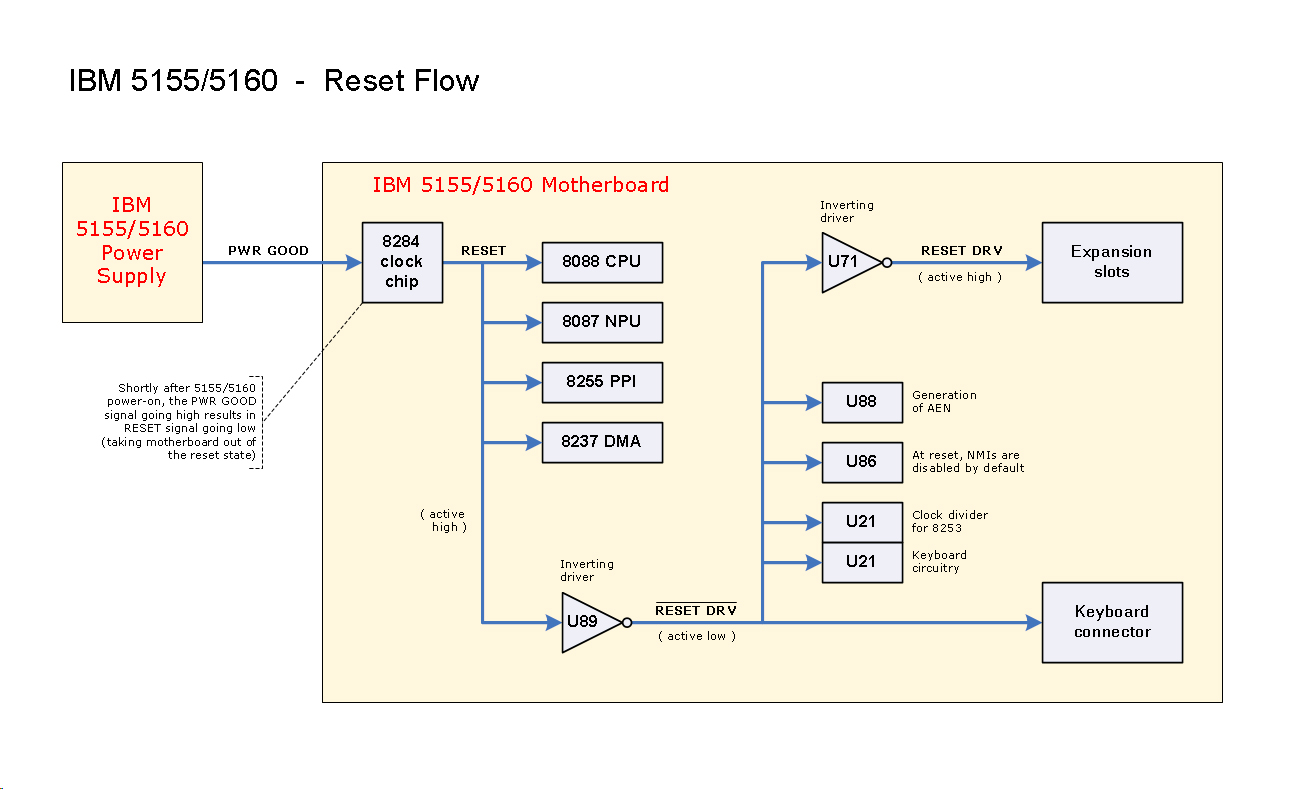
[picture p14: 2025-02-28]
Simplyfied_Diagram/5160_reset_flow.jpg

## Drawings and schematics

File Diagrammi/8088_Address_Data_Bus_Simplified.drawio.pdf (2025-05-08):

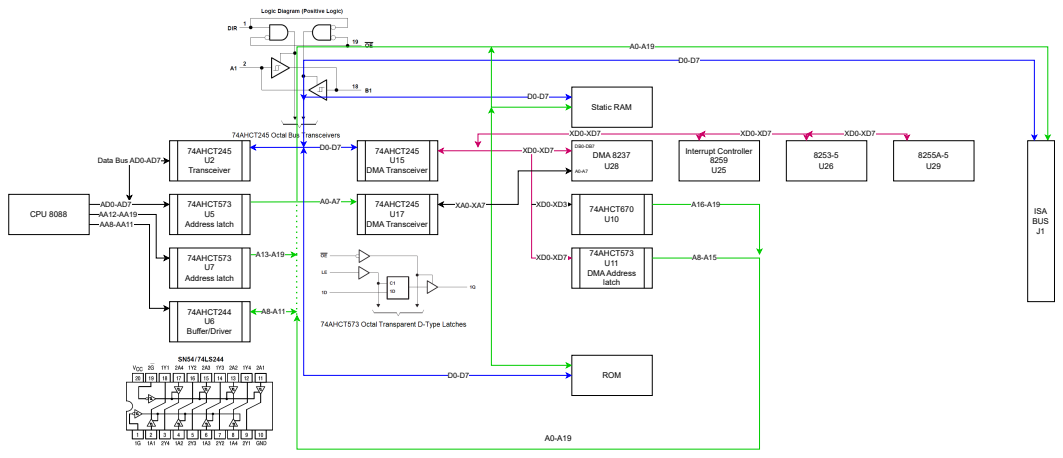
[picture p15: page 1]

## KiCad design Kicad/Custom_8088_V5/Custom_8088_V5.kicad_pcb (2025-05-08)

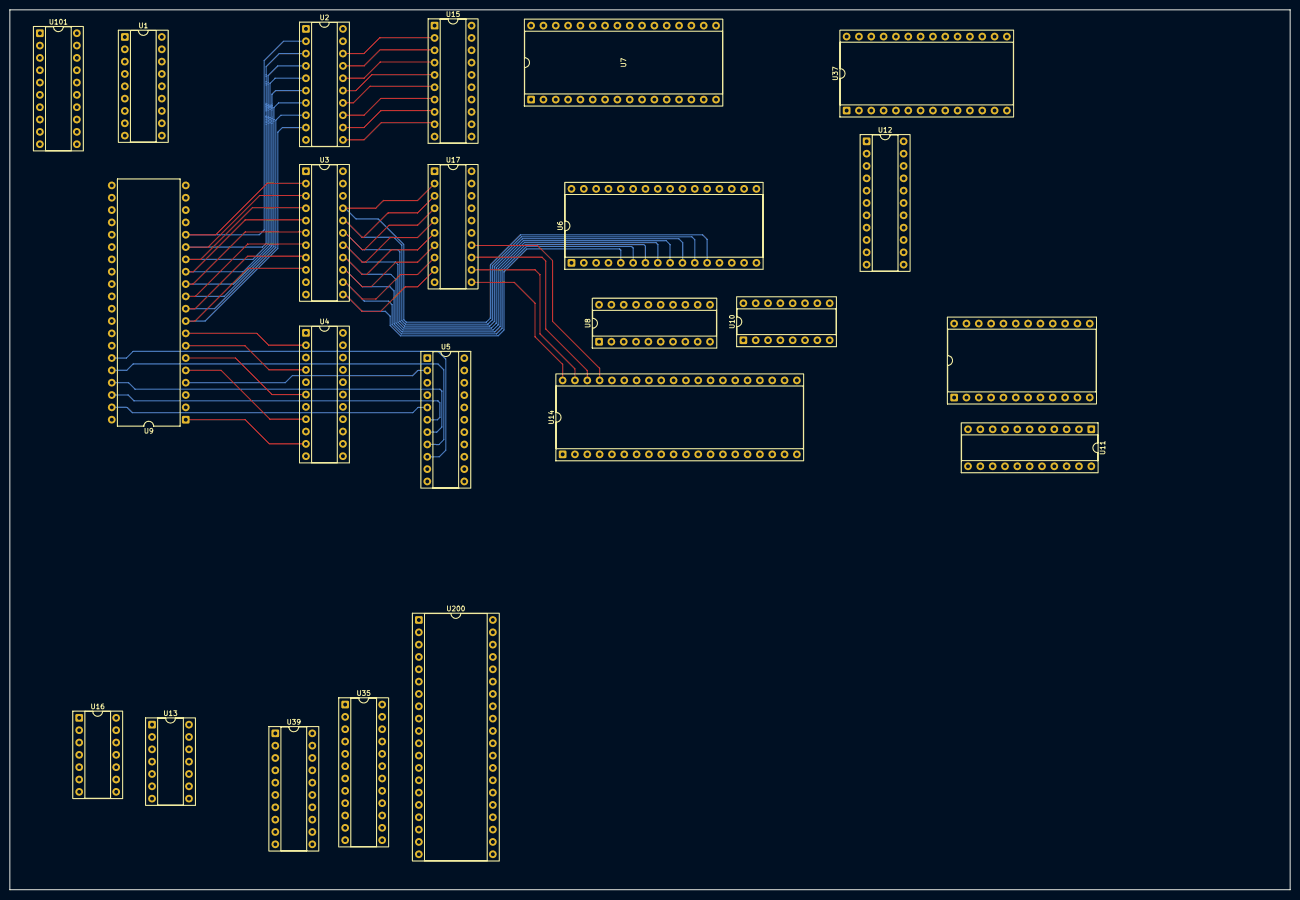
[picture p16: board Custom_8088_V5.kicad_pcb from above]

Board: 2 copper layers, 263.8 x 181.2 mm, 23 parts (0 on the bottom side), 91 nets.

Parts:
U1: 82C84A; DIP-18_W7.62mm_Socket
U2, U15, U17, U39: 74AHCT245N; DIP-20_W7.62mm_Socket
U3, U5, U11: SN74AHCT573N; DIP-22_W7.62mm_Socket
U4, U12: SN72AHCT244N; DIP-22_W7.62mm_Socket
U6: HM628512C; DIP-32_W15.24mm_Socket
U7: AT29C010A-90PC; DIP-32_W15.24mm_Socket
U8: 8288; DIP-20_W7.62mm_Socket
U9: 8088_Max_Mode; DIP-40_W15.24mm
U10: 74HCT670; DIP-16_W7.62mm_Socket
U13: 74LS06N; DIP-14_W7.62mm_Socket
U14: 8237A; DIP-40_W15.24mm_Socket
U16: 74AHCT04; DIP-14_W7.62mm_Socket
U35: ATF22V10; DIP-24_W7.62mm_Socket
U37: 82C59A; DIP-28_W15.24mm_Socket
U38: TMP82C54P-2; DIP-24_W15.24mm_Socket
U101: ATF16V8C; DIP-20_W7.62mm_Socket
U200: VT82C42; DIP-40_W15.24mm_Socket

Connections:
+5V: U1.7 (~AEN2), U1.18 (Vcc), U2.20 (Vcc), U3.20 (Vcc), U4.20 (Vcc), U5.20 (Vcc), U6.32 (VCC), U7.32 (VCC), U8.20 (Vcc), U9.40 (VCC), U10.16 (Vcc), U11.20 (Vcc), U12.10 (GND), U12.20 (Vcc), U13.14 (VCC), U14.5 (PIN5), U14.31 (VCC), U15.20 (Vcc), U17.20 (Vcc), U37.28 (VCC), U38.24 (VCC), U101.20 (VCC), U200.40 (Vcc)
/A0: U3.19 (1Q), U6.12 (A0), U12.16 (1Y2), U17.2 (A1)
/A1: U3.18 (2Q), U6.11 (A1), U12.14 (1Y3), U17.3 (A2)
/A2: U3.17 (3Q), U6.10 (A2), U12.12 (1Y4), U17.4 (A3)
/A3: U3.16 (4Q), U6.9 (A3), U12.9 (2Y1), U17.5 (A4)
/A4: U3.15 (5Q), U6.8 (A4), U12.7 (2Y2), U17.6 (A5)
/A5: U3.14 (6Q), U6.7 (A5), U12.5 (2Y3), U17.7 (A6)
/A6: U3.13 (7Q), U6.6 (A6), U12.3 (2Y4), U17.8 (A7)
/A7: U3.12 (8Q), U6.5 (A7), U17.9 (A8)
/A8: U4.18 (1Y1), U6.27 (A8), U11.19 (1Q)
/A9: U4.16 (1Y2), U6.26 (A9), U11.18 (2Q)
/A10: U4.14 (1Y3), U6.23 (A10), U11.17 (3Q)
/A11: U4.12 (1Y4), U6.25 (A11), U11.16 (4Q)
/A12: U5.19 (1Q), U6.4 (A12), U11.15 (5Q)
/A13: U5.18 (2Q), U6.28 (A13), U11.14 (6Q)
/A14: U5.17 (3Q), U6.3 (A14), U11.13 (7Q)
/A15: U5.16 (4Q), U6.31 (A15), U11.12 (8Q)
/A16: U5.15 (5Q), U6.2 (A16), U10.10 (Q0)
/A17: U5.14 (6Q), U6.30 (A17), U10.9 (Q1)
/A18: U5.13 (7Q), U6.1 (A18), U10.7 (Q2)
/A19: U5.12 (8Q), U10.6 (Q3)
/AENBRD: U3.1 (~OE), U4.1 (1~OE), U5.1 (~OE), U8.6 (~AEN), U8.14 (~INTA), U15.19 (~OE), U37.27 (A0)
/ALE: U3.11 (LE), U5.11 (LE), U8.5 (ALE)
/CLK88: U1.8 (CLK), U8.2 (CLK), U9.19 (CLK), U101.2 (I1)
/D0: U2.18 (B1), U6.13 (I/O0), U15.2 (A1)
/D1: U2.17 (B2), U6.14 (I/O1), U15.3 (A2)
/D2: U2.16 (B3), U6.15 (I/O2), U15.4 (A3)
/D3: U2.15 (B4), U6.17 (I/O3), U15.5 (A4)
/D4: U2.14 (B5), U6.18 (I/O4), U15.6 (A5)
/D5: U2.13 (B6), U6.19 (I/O5), U15.7 (A6)
/D6: U2.12 (B7), U6.20 (I/O6), U15.8 (A7)
/D7: U2.11 (B8), U6.21 (I/O7), U15.9 (A8)
/DMA ENABLE: U10.11 (~RE), U11.1 (~OE), U12.2 (1A1), U12.18 (1Y1)
/DMACLK: U14.12 (CLK), U101.19 (I/O)
/INTR: U9.17 (NMI), U37.18 (IR0)
/NC: U8.9 (~MWTC), U8.11 (~IOWC), U8.17 (MCE/~PDEN), U9.32 (~RD), U9.34 (HIGH), U14.9 (AEN), U37.16 (~SP/~EN)
/XA0: U7.12 (A0), U10.14 (WA), U12.4 (1A2), U14.32 (A0), U17.18 (B1)
/XA1: U7.11 (A1), U10.13 (WB), U12.6 (1A3), U14.33 (A1), U17.17 (B2)
/XA2: U7.10 (A2), U12.8 (1A4), U14.34 (A2), U17.16 (B3)
/XA3: U7.9 (A3), U12.11 (2A1), U14.35 (A3), U17.15 (B4)
/XA4: U7.8 (A4), U12.13 (2A2), U14.37 (A4), U17.14 (B5)
/XA5: U7.7 (A5), U12.15 (2A3), U14.38 (A5), U17.13 (B6)
/XA6: U7.6 (A6), U12.17 (2A4), U14.39 (A6), U17.12 (B7)
/XA7: U7.5 (A7), U14.40 (A7), U17.11 (B8)
/XD0: U7.13 (I/O0), U10.15 (D0), U11.2 (1D), U14.30 (DB0), U15.18 (B1), U37.10 (D1), U38.8 (D0)
/XD1: U7.14 (I/O1), U10.1 (D1), U11.3 (2D), U14.29 (DB1), U15.17 (B2), U37.9 (D2), U38.7 (D1)
/XD2: U7.15 (I/O2), U10.2 (D2), U11.4 (3D), U14.28 (DB2), U15.16 (B3), U37.8 (D3), U38.4 (D2)
/XD3: U7.17 (I/O3), U10.3 (D3), U11.5 (4D), U14.27 (DB3), U15.15 (B4), U37.7 (D4), U38.5 (D3)
/XD4: U7.18 (I/O4), U11.6 (5D), U14.26 (DB4), U15.14 (B5), U37.6 (D5)
/XD5: U7.19 (I/O5), U11.7 (6D), U14.23 (DB5), U15.13 (B6), U37.5 (D6), U38.3 (D5)
/XD6: U7.20 (I/O6), U11.8 (7D), U14.22 (DB6), U15.12 (B7), U37.4 (D7), U38.2 (D6)
/XD7: U7.21 (I/O7), U11.9 (8D), U14.21 (DB7), U15.11 (B8), U37.3 (~RD), U38.1 (D7)
/~AEN: U8.15 (CEN), U17.1 (DIR)
/~DACK2: U10.4 (RB), U14.14 (DACK2)
/~DACK3: U10.5 (RA), U14.15 (DACK3)
/~MEMR: U6.24 (~OE), U7.24 (~OE), U8.7 (~MRDC)
/~MEMW: U6.29 (~WE), U7.31 (~WE), U8.8 (~AMWC)
/~XIOR: U14.1 (~IOR), U37.2 (~WR), U38.22 (~RD)
/~XIOW: U14.2 (~IOW), U37.1 (~CS), U38.23 (~WR)
GND: U1.1 (CSYNC), U1.6 (RDY2), U1.9 (GND), U1.13 (F/~C), U1.15 (~ASYNC), U2.10 (GND), U3.10 (GND), U4.10 (GND), U5.10 (GND), U6.16 (GND), U7.16 (GND), U8.1 (IOB), U8.10 (GND), U9.1 (GND), U9.20 (GND), U9.33 (MN/~MX), U10.8 (GND), U11.10 (GND), U13.7 (GND), U14.19 (DREQ0), U14.20 (VSS), U15.10 (GND), U17.10 (GND), U17.19 (~OE), U37.14 (GND), U38.12 (GND), U101.10 (GND), U101.11 (I9/~OE), U200.20 (GND)
unnamed: U1.2 (PCLK), U101.1 (I/CLK)
unnamed: U1.5 (READY), U9.22 (READY)
unnamed: U1.10 (RESET), U9.21 (RESET), U14.13 (RESET), U101.3 (I2)
unnamed: U2.2 (A1), U3.2 (1D), U9.16 (AD0)
unnamed: U2.3 (A2), U3.3 (2D), U9.15 (AD1)
unnamed: U2.4 (A3), U3.4 (3D), U9.14 (AD2)
unnamed: U2.5 (A4), U3.5 (4D), U9.13 (AD3)
unnamed: U2.6 (A5), U3.6 (5D), U9.12 (AD4)
unnamed: U2.7 (A6), U3.7 (6D), U9.11 (AD5)
unnamed: U2.8 (A7), U3.8 (7D), U9.10 (AD6)
unnamed: U2.9 (A8), U3.9 (8D), U9.9 (AD7)
unnamed: U2.1 (DIR), U8.4 (DT/~R)
unnamed: U2.19 (~OE), U16.2
unnamed: U4.2 (1A1), U9.8 (A8)
unnamed: U4.4 (1A2), U9.7 (A9)
unnamed: U4.6 (1A3), U9.6 (A10)
unnamed: U4.8 (1A4), U9.5 (A11)
unnamed: U5.2 (1D), U9.4 (A12)
unnamed: U5.3 (2D), U9.3 (A13)
unnamed: U5.4 (3D), U9.2 (A14)
unnamed: U5.5 (4D), U9.39 (A15)
unnamed: U5.6 (5D), U9.38 (A16/S3)
unnamed: U5.7 (6D), U9.37 (A17/S4)
unnamed: U5.8 (7D), U9.36 (A18/S5)
unnamed: U5.9 (8D), U9.35 (A19/S6)
unnamed: U8.16 (DEN), U16.1
unnamed: U8.19 (~S0), U9.26 (~S0)
unnamed: U8.3 (~S1), U9.27 (~S1)
unnamed: U8.18 (~S2), U9.28 (~S2)
unnamed: U11.11 (LE), U14.8 (ADSTB)
unnamed: U14.36 (~EOP), U16.3
